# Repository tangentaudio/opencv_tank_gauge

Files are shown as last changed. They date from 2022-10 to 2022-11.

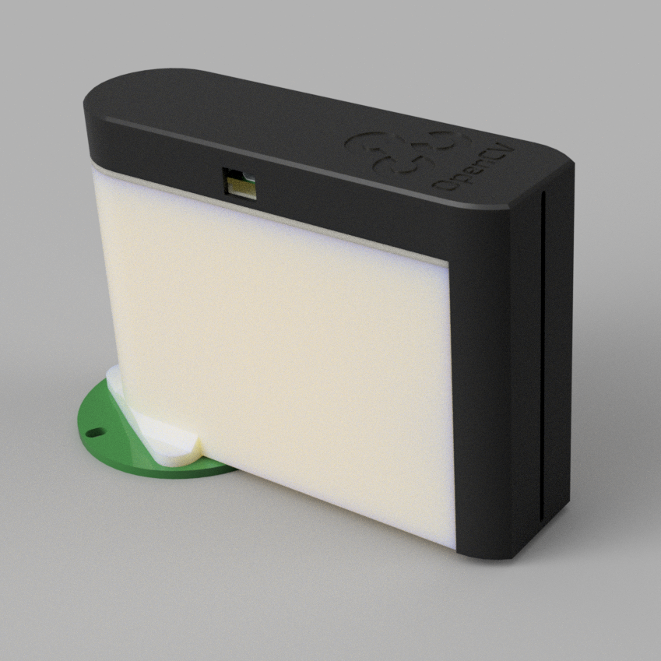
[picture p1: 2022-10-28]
mechanical/enclosure.png

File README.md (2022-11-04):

# OpenCV Oil Tank Gauge Reader

OpenCV Oil Tank Gauge Reader

## Features
- Raspberry Pi Zero W with Official Raspberry Pi Camera 2
- Custom 3D printed enclosure and tank mount, using magnets for quick removal
- 16 RGB LED display to show tank level and warnings
- Real-time CV parameter tuning with live video update in browser window
- Home Assistant API integration
- REST API

## Documentation

Full mechanical assembly, electronics assembly, and software installation instructions are located on the [Project Wiki](https://github.com/tangentaudio/opencv_tank_gauge/wiki)

## Software Quick Start

Advanced users can skip straight to the installer script, which installs all pre-requisites and configures system services.  Find it at `install.sh` in the project root directory.  This is best done on a fresh Raspberry Pi OS Lite 32-bit installation. [Full installation instructions](https://github.com/tangentaudio/opencv_tank_gauge/wiki/Software-Installation) are on the wiki.

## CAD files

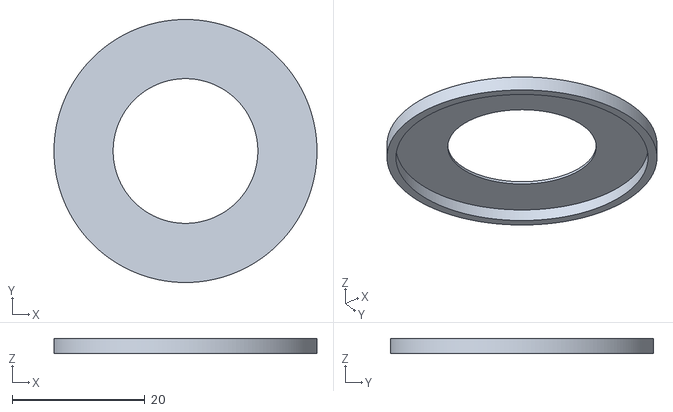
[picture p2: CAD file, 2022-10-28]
mechanical/BaseCover.stl
39.6 x 39.6 x 2.20

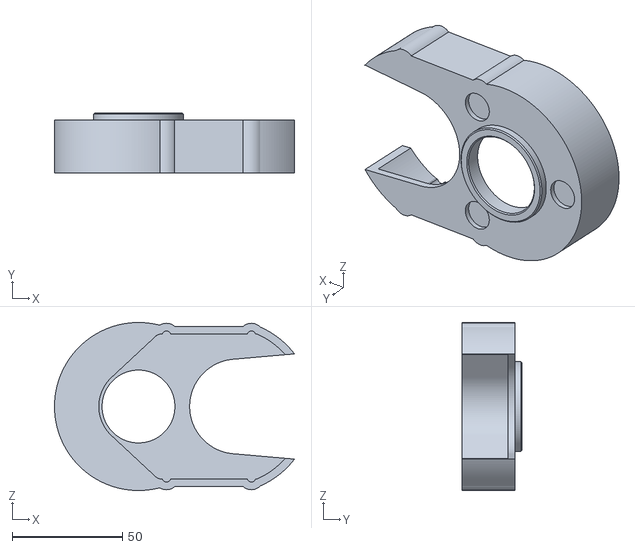
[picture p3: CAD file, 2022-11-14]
mechanical/contrib/Mounting Bracket Combo Vent Gauge.stl
108.8 x 27.4 x 76.2

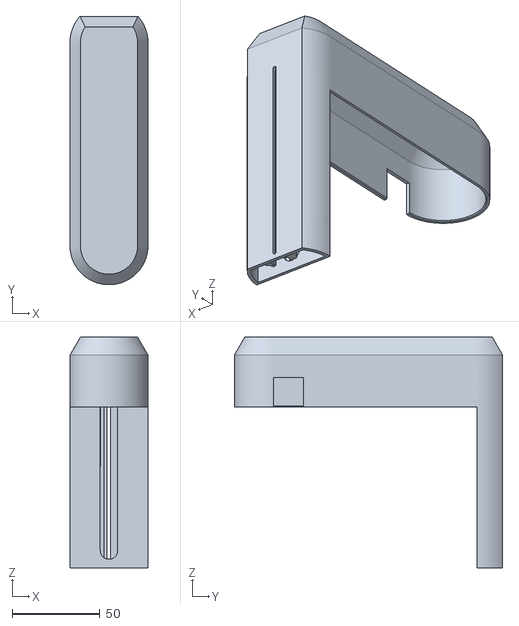
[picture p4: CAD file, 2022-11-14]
mechanical/contrib/Waveshare PoE Hat/Lid Top_PoE.stl
44.6 x 153.4 x 132.0

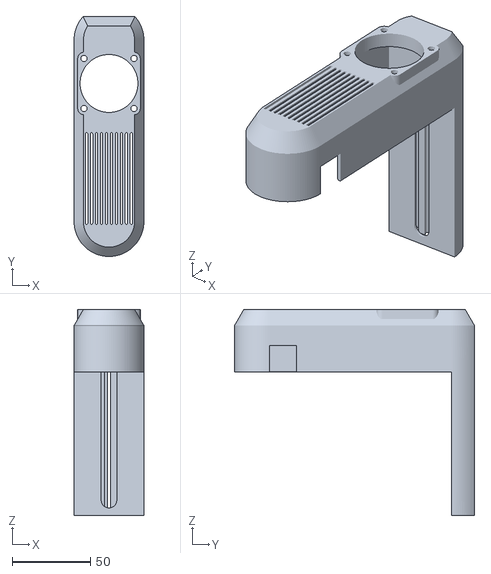
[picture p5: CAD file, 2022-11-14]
mechanical/contrib/Waveshare PoE Hat/Lid Top_PoE_Fan.stl
44.6 x 153.4 x 132.0

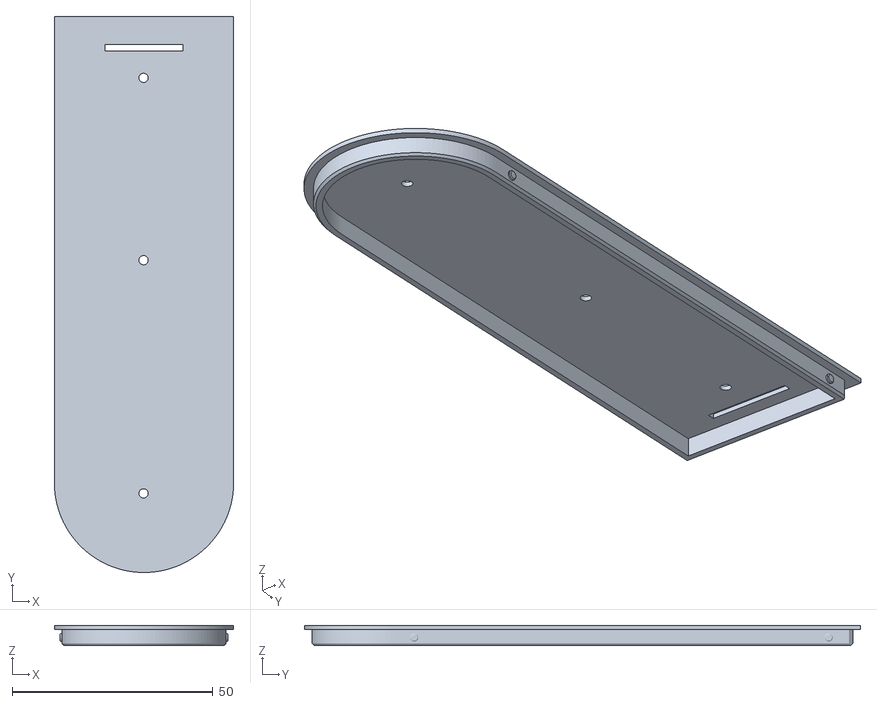
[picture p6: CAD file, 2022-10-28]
mechanical/LidLower.stl
44.6 x 138.4 x 5.00

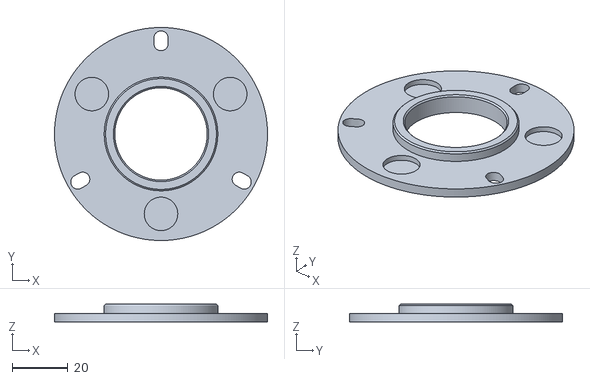
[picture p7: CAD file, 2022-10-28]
mechanical/BaseMount.stl
76.2 x 76.2 x 6.35

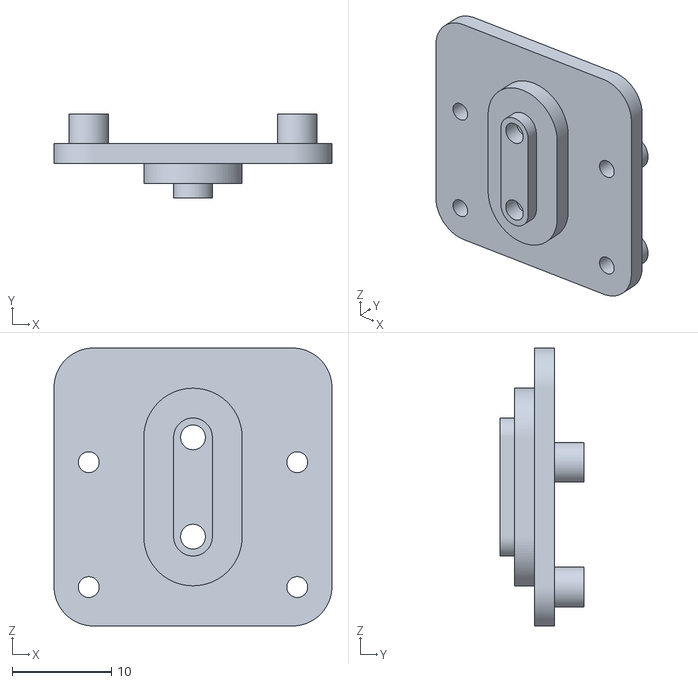
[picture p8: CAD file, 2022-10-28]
mechanical/CameraMount.stl
28.0 x 8.50 x 28.0

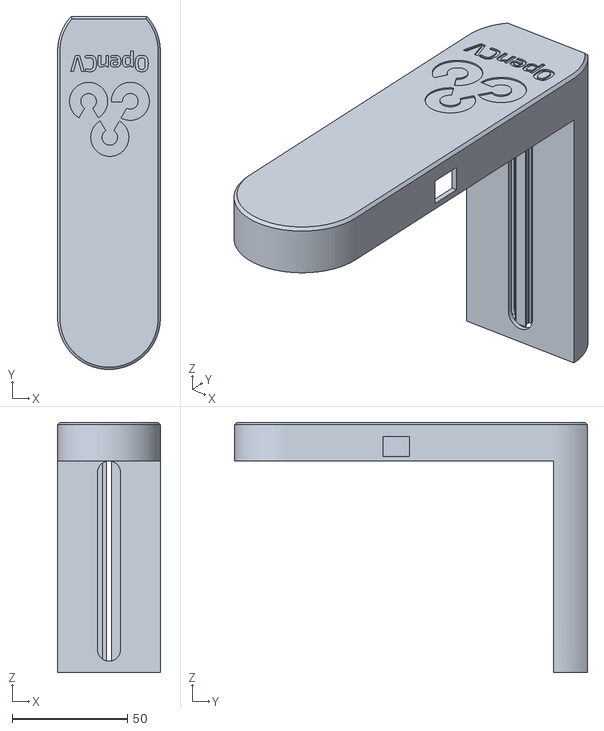
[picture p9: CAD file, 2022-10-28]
mechanical/LidTop.stl
44.6 x 153.4 x 108.8

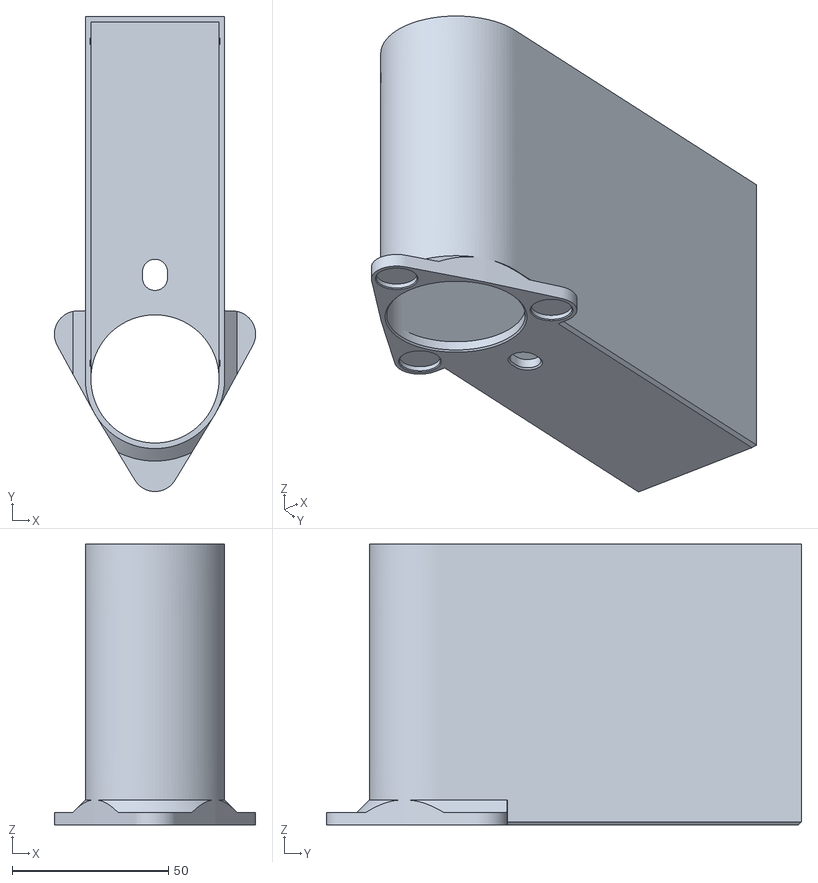
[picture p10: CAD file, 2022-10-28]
mechanical/WallStructure.stl
64.5 x 152.2 x 90.0

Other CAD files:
mechanical/LidMid.stl

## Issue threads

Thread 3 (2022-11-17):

Feature request: adjust target colors for IR cameras

timnunes, 2022-11-17:
I have an IR camera (no IR filter and IR lights that are always on) which is black/white, maybe a pinkish hue. I'm able to get this project working, but only if I shine a bright light directly on the gauge.

It detects the line segments easily (they come across as black), but the float is white with just the IR lights.

Is there a way to have it look for shades of white as opposed to shades of red?

I looked through gauge.py and found the following lines which I might be able to adjust:

```
ind_lower_red = np.array([145,112,0])
ind_upper_red = np.array([179,255,255])
```
I'm not sure what the values would be once converted to HSV.

Thanks.

tangentaudio, 2022-11-17:
Hi @timnunes,
Since the IR camera is essentially black and white, it might take a different approach to detect the position of the indicator than the one I used to find red pixels.  I'm not sure an HSV range will work well.

A good first step would be to get an unprocessed image from your setup.  Easiest thing to do would be to stop the gauge-cv service via systemctl and then run `raspistill --width 800 --height 608 --encoding png --output test.png`

Once you've got test.png, you can drop it into a comment here, e.g.:

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

timnunes, 2022-11-17:
Thanks for the reply.

First a picture with the just the built in IR lights:
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

Next is a picture with a lamp shining directly on the gauge:
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

For fun, a screenshot of the web app with the lamp turned OFF:
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

...and a screenshot of the web app with the lamp turned ON:
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

timnunes, 2022-11-18:
I may not be a smart man, but it seems that I have figured out how to adjust gauge.py to fit my needs. I'll add my edits below for anyone else looking.

In summary, I commented out the line that converts to HSV, adjusted the HTML color codes to match my camera output, and changed the reference to "ind_crop_hsv" to "ind_crop", since I'm skipping the conversion to HSV.

Thanks @tangentaudio, not only for this really great project, but also for pointing me in the right direction.

```
        # find the red indicator with a mask and range
        #ind_crop_hsv = cv2.cvtColor(ind_crop, cv2.COLOR_BGR2HSV) (commented out so no conversion happens. Optional, since we remove reference to "ind_crop_hsv" further down)

        #use an online tool to find the html colors of the float indicator in your image and adjust accordingly
        ind_lower_red = np.array([183,130,204])
        ind_upper_red = np.array([255,255,255])

        #Changed the reference from "ind_crop_hsv" to "ind_crop".
        ind_red_mask = cv2.inRange(ind_crop, ind_lower_red, ind_upper_red)
```

tangentaudio, 2022-11-18:
Glad to hear you got it working!  At some point I will make a round of improvements to the code and try to make it flexible enough to work with a setup like yours without code changes.  Cheers.

Closed 2022-11-18.

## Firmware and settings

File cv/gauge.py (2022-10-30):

#!/usr/bin/env python

import redis
from picamera import PiCamera
from picamera.array import PiRGBArray
import cv2
import numpy as np
from datetime import datetime
import time
from rich.progress import Progress

class GaugeCV:

    REQUIRED_CONFIG_KEYS = \
        ['rotate_angle',
         'crop_x1',
         'crop_x2',
         'crop_y1',
         'crop_y2',
         'slice_x1',
         'slice_x2',
         'indicator_blur',
         'tick_blur',
         'tick_threshold',
         'indicator_threshold',
         'level_average_points',
         'level_max_deviation']

    def __init__(self):
        GaugeCV.REQUIRED_CONFIG_KEYS.sort()
        
        self.rd = redis.Redis(host='localhost', port=6379, db=0)
        
        self.level_avg_win = []
        self.config = {}
        self.camera = None
        self.cam_buf = None
        self.preview = None
        self.avg = 0.0
        self.avg_update_time = None

        self.mean = None
        self.std_dev = None
        self.no_outliers = None

    def run(self):
       
        with Progress() as progress:
            with PiCamera() as self.camera:
                self.camera.resolution = (800,608)
                with PiRGBArray(self.camera, size=(800, 608)) as self.cam_buf:
                    t1 = progress.add_task("Get config from redis", total=None)
                
                    while not self.get_config():
                        time.sleep(1)

                    progress.remove_task(t1)
                    progress.console.print("Got config from redis.")

                    last_frames = 0
                    t2 = progress.add_task("Processing image frames", total=None)

                    while True:
                        if not self.get_config():
                            progress.console.print("Can't get config from redis.  Quitting.")
                            exit

                        num_frames = int(self.config['level_average_points'])

                        if last_frames != num_frames:
                            progress.reset(t2, total=num_frames)
                            last_frames = num_frames
                        
                        if self.process_image():
                            progress.console.print(f"Average level {round(self.avg, 2)}%")
                            progress.reset(t2, total=num_frames)

                        progress.advance(t2)
                        
    def get_config(self):
        have_keys = []
        for key in GaugeCV.REQUIRED_CONFIG_KEYS:
            value = self.rd.get('_config_' + key)
            if value is not None:
                value = value.decode('utf-8')
                self.config[key] = float(value)
                have_keys.append(key)

        have_keys.sort()

        return GaugeCV.REQUIRED_CONFIG_KEYS == have_keys
                    
    def config_int(self, key, default=0):
        if key in self.config:
            return int(self.config[key])
        else:
            return default

    def contour_area(self, contours):
        cnt_area = []
        for i in range(0,len(contours),1):
            cnt_area.append(cv2.contourArea(contours[i]))
        list.sort(cnt_area, reverse=True)
        return cnt_area    

    def interpolate(self, tick_contours, indicator_contours, image):
        slice_x1 = self.config_int('slice_x1')
        slice_x2 = self.config_int('slice_x2')
        crop_x1 = self.config_int('crop_x1')
        crop_x2 = self.config_int('crop_x2')
        crop_y1 = self.config_int('crop_y1')
        
        tick_fp = [100.0,75.0,50.0,25.0,0.0]
        tick_yvals = []
        indicator_yval = 0

        image_h = image.shape[0]
        image_w = image.shape[1]
        legend_w = 25

        if len(tick_contours) < 5 or len(indicator_contours) < 1:
            return [None, image]

        tick_cnt_area = self.contour_area(tick_contours)
        for i in range(0, len(tick_contours), 1):
            tick_contour = tick_contours[i]
            if (cv2.contourArea(tick_contour) >= tick_cnt_area[4]):
                x,y,w,h = cv2.boundingRect(tick_contour)
                tick_yval = y + h//2
                tick_yvals.append(tick_yval)

        ind_cnt_area = self.contour_area(indicator_contours)
        for i in range(0, len(indicator_contours), 1):
            indicator_contour = indicator_contours[i]
            if (cv2.contourArea(indicator_contour) >= ind_cnt_area[0]):
                x,y,w,h = cv2.boundingRect(indicator_contour)
                indicator_yval = y + h//2

        tick_yvals.sort()

        if len(tick_yvals) == 5:

            font = cv2.FONT_HERSHEY_SIMPLEX

            for i in range(0, len(tick_yvals), 1):
                yval = tick_yvals[i] + crop_y1
                fpval = tick_fp[i]

                image=cv2.rectangle(image,(slice_x2,yval),(slice_x2 + legend_w,yval),(0,255,0),2)

                image=cv2.putText(image, "{:.0f}%".format(fpval), (slice_x2+legend_w,yval+10), font, 1.0, (0,255,0), 2, cv2.LINE_AA) 

            level = np.interp([indicator_yval], tick_yvals, tick_fp)[0]

            image=cv2.rectangle(image,(crop_x1-legend_w,indicator_yval+crop_y1),(crop_x2,indicator_yval + crop_y1),(0,0,255),3)
            image=cv2.putText(image, "{:.2f}%".format(level), (crop_x1-legend_w-100,indicator_yval+crop_y1+10), font, 1.0, (0,0,255), 2, cv2.LINE_AA) 

            now = datetime.now()
            dt_string = now.strftime("%m/%d/%Y %H:%M:%S")        
            image=cv2.putText(image, dt_string, (0, image_h - 5), font, 1.0, (32,32,32), 2, cv2.LINE_AA) 

            return [level, image]
        return [None, image]

    def rotate_image(self, image, angle):
      image_center = tuple(np.array(image.shape[1::-1]) / 2)
      rot_mat = cv2.getRotationMatrix2D(image_center, angle, 1.0)
      result = cv2.warpAffine(image, rot_mat, image.shape[1::-1], flags=cv2.INTER_LINEAR)
      return result

    def preview_render_list(self, preview, l, x, y = 0, color=(0,0,0)):
        if preview is not None:
            pi = 0
            font = cv2.FONT_HERSHEY_SIMPLEX
            for pv in l:
                preview = cv2.putText(preview, "{:02d}: {:.2f}".format(pi, pv), (x, y + (pi+1) * 16), font, 0.5, color, 1, cv2.LINE_AA)
                pi = pi + 1
        
        return preview

    def preview_render_stats(self, preview, mean, std_dev, mean_clean):
        x = 600
        y = 0
        if preview is not None:
            font = cv2.FONT_HERSHEY_SIMPLEX
            preview = cv2.putText(preview, "MEAN: {:.2f}".format(mean), (x, y + 16), font, 0.5, (128,0,0), 1, cv2.LINE_AA)
            preview = cv2.putText(preview, "STD DEV: {:.2f}".format(std_dev), (x, y + 32), font, 0.5, (128,0,0), 1, cv2.LINE_AA)

            preview = cv2.putText(preview, "AVG: {:.2f}".format(mean_clean), (x, y + 48), font, 0.5, (0,0,128), 1, cv2.LINE_AA)
        return preview
    
    def average_level(self, level, preview):
        level_average_points = self.config_int('level_average_points')
        max_deviations = self.config['level_max_deviation']
        
        if len(self.level_avg_win) < level_average_points:
            self.level_avg_win.append(level)

            preview = self.preview_render_list(preview, self.level_avg_win, 0)

            if self.mean is not None and self.std_dev is not None and self.no_outliers is not None:
                preview = self.preview_render_list(preview, self.no_outliers, 100, 0, (64,0,0))
                preview = self.preview_render_stats(preview, self.mean, self.std_dev, self.avg)
                
        else:
            avg_array = np.array(self.level_avg_win)
            mean = np.mean(avg_array)
            standard_deviation = np.std(avg_array)
            distance_from_mean = abs(avg_array - mean)

            not_outlier = distance_from_mean <= max_deviations * standard_deviation
            no_outliers = avg_array[not_outlier]

            preview = self.preview_render_list(preview, self.level_avg_win, 0, 0)
            preview = self.preview_render_list(preview, no_outliers, 100, 0, (64,0,0))
            
            avg = np.mean(no_outliers)

            preview = self.preview_render_stats(preview, mean, standard_deviation, avg)

            self.mean = mean
            self.std_dev = standard_deviation
            self.no_outliers = no_outliers
            
            self.level_avg_win = []

            return avg, preview

        return None, preview

    def process_image(self):
        crop_x1 = self.config_int('crop_x1')
        crop_y1 = self.config_int('crop_y1')
        crop_x2 = self.config_int('crop_x2')
        crop_y2 = self.config_int('crop_y2')
        slice_x1 = self.config_int('slice_x1')
        slice_x2 = self.config_int('slice_x2')
        rotate_angle = self.config['rotate_angle']
        tick_blur = int(self.config['tick_blur'])
        indicator_blur = int(self.config['indicator_blur'])
        tick_threshold = self.config['tick_threshold']
        indicator_threshold = self.config['indicator_threshold']
        
        # capture a frame from the camera
        self.cam_buf.truncate(0)
        self.camera.capture(self.cam_buf, format="bgr")
        frame = self.cam_buf.array

        # crop and rotate the image to correct, then 180 degrees because of upside down camera
        image = self.rotate_image(frame, rotate_angle)
        image = cv2.rotate(image, 1, cv2.ROTATE_180)

        # create a preview image for the web stream
        preview = image.copy()

        # crop a slice to find the tick marks
        tick_crop = image[crop_y1:crop_y2, slice_x1:slice_x2]

        # convert to an inverted threshold image to find the tick marks
        tick_crop_gray = cv2.cvtColor(tick_crop, cv2.COLOR_BGR2GRAY)
        tick_crop_gray = cv2.blur(tick_crop_gray, (tick_blur,tick_blur), cv2.BORDER_DEFAULT)
        ret, tick_thresh = cv2.threshold(tick_crop_gray, tick_threshold, 255, cv2.THRESH_BINARY)
        tick_thresh_inv = cv2.bitwise_not(tick_thresh)

        # copy the inverted threshold image onto the preview image in the correct location
        tick_thresh_inv_bgr = cv2.cvtColor(tick_thresh_inv, cv2.COLOR_GRAY2BGR)
        tick_thresh_inv_bgr = cv2.bitwise_or(tick_crop, tick_thresh_inv_bgr)
        preview[crop_y1:crop_y1 + tick_crop.shape[0], slice_x1:slice_x1+tick_crop.shape[1]] = tick_thresh_inv_bgr

        # find contours that represent the tick marks
        tick_contours, tick_hierarchy = cv2.findContours(image=tick_thresh_inv, mode=cv2.RETR_TREE, method=cv2.CHAIN_APPROX_NONE)

        # crop a rectangle from the image to find the indicator
        ind_crop = image[crop_y1:crop_y2, crop_x1:crop_x2]

        # find the red indicator with a mask and range
        ind_crop_hsv = cv2.cvtColor(ind_crop, cv2.COLOR_BGR2HSV)

        ind_lower_red = np.array([145,112,0])
        ind_upper_red = np.array([179,255,255])

        ind_red_mask = cv2.inRange(ind_crop_hsv, ind_lower_red, ind_upper_red)
        ind_masked = cv2.bitwise_and(ind_crop, ind_crop, mask=ind_red_mask)
        ind_masked = cv2.blur(ind_masked, (indicator_blur,indicator_blur), cv2.BORDER_DEFAULT)

        ind_masked_gray = cv2.cvtColor(ind_masked, cv2.COLOR_BGR2GRAY)
        ret, ind_masked_thresh = cv2.threshold(ind_masked_gray, indicator_threshold, 255, cv2.THRESH_BINARY)

        # copy the indicator threshold image onto the preview
        prev_ind_thresh = cv2.cvtColor(ind_masked_thresh, cv2.COLOR_GRAY2BGR)
        prev_ind_thresh = cv2.bitwise_or(ind_crop, prev_ind_thresh)

        preview[crop_y1:crop_y1 + prev_ind_thresh.shape[0], crop_x1:crop_x1+prev_ind_thresh.shape[1]] = prev_ind_thresh

        # find contours for the indicator
        ind_contours, ind_hierarchy = cv2.findContours(image=ind_masked_thresh, mode=cv2.RETR_TREE, method=cv2.CHAIN_APPROX_SIMPLE)

        # draw the crops on the preview
        preview = cv2.rectangle(preview, (crop_x1, crop_y1), (crop_x2, crop_y2), (0,32,192), 2)
        preview = cv2.rectangle(preview, (slice_x1, crop_y1), (slice_x2, crop_y2), (0,192,0), 2)

        level, preview = self.interpolate(tick_contours, ind_contours, preview)

        avg = None
        if level is not None:
            avg, preview = self.average_level(level, preview)
            if avg is not None:
                
                now = str(datetime.now())
                self.rd.set('avg_level', avg)
                self.rd.set('avg_update_time', now)

                self.rd.publish('avg_level', avg)
                self.rd.publish('avg_update_time', now)

                self.avg = avg
                self.avg_update_time = now
                
        if preview is not None:
            ret, buffer = cv2.imencode('.jpg', preview)
            self.rd.set('encoded_preview', buffer.tobytes())
            self.rd.publish('encoded_preview', 'updated')


        if avg is not None:
            self.rd.publish('encoded_preview', 'updated')            
            return True
        
        return False

    def close(self):
        if self.camera is not None:
            self.camera.close()

if __name__ == '__main__':
    cv = GaugeCV()
    cv.run()
    

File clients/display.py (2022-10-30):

#!/usr/bin/env python

import time
from datetime import datetime
import board
import neopixel
from threading import Thread,Lock
from enum import Enum
import redis
import os

class States(Enum):
    INIT = 1
    ERROR = 2
    QUERY = 3
    LEVEL = 4
    SHUTDOWN = 5

class GaugePixels:
    def __init__(self):
        self.pixels = neopixel.NeoPixel(board.D21, 16, brightness=0.1, pixel_order=neopixel.GRB, auto_write=False)

        self.state = States.INIT
        self.state_update = True
        self.phase = 0
        self.level = 0.0
        self.warn = False
        self.lock = Lock()
        
        t = Thread(target=self.thread_func)
        t.start()

        
    def display_level(self, level, show=True):
        print("display level={l}".format(l=level))
        self.pixels.fill((0,0,0))

        warn = False
        
        color = (0,255,0)
        if level > 0.0 and level < 30.0:
            color = (255, 0, 0)
            warn = True
        elif level >= 30 and level < 70:
            color = (192, 192, 0)
            
        last = int(15 * (level / 100.0)) + 1;
            
        for pixel in range(0,last,1):
            self.pixels[pixel] = color

        if show:
            self.pixels.show()
        
        return [warn, last]
       
        
    def thread_func(self):
        while True:
            with self.lock:
                state = self.state
                state_update = self.state_update
                phase = self.phase
                level = self.level
                warn = self.warn

            if state_update:
                phase = 0
            else:
                phase = phase + 1
                
            if state == States.INIT:
                if phase == 0:
                    self.pixels.fill((0,0,255))
                    self.pixels.show()
                elif phase == 10:
                    self.pixels.fill((0,0,0))
                    self.pixels.show()
                pass
            elif state == States.ERROR:
                if phase == 0:
                    self.pixels.fill((255,0,0))
                    self.pixels.show()
                elif phase == 5:
                    self.pixels.fill((0,0,0))
                    self.pixels.show()
                elif phase == 10:
                    phase = 0
                pass
            elif state == States.QUERY:
                if phase == 0:
                    self.pixels.fill((0,0,0))
                    self.pixels.show()
                elif phase == 3:
                    self.pixels[6] = (0,0,255)
                    self.pixels[7] = (255,255,255)
                    self.pixels[8] = (0,0,255)
                    self.pixels.show()
                elif phase == 6:
                    phase = 0
                    
            elif state == States.LEVEL:
                if phase == 0:
                    # show level and top LED as blue to indicate an update
                    warn, last = self.display_level(level, False)
                    self.pixels[15] = (0, 0, 255)
                    self.pixels.show()

                elif phase == 10:
                    # show the plain level
                    warn, last = self.display_level(level, True)
                    
                elif phase == 15:
                    # blink the level if in warning state
                    if warn:
                        self.pixels.fill((0,0,0))
                        self.pixels.show()

                elif phase == 20:
                    # jump back to plain level display in warning state
                    if warn:
                        phase = 10
                    
            elif state == States.SHUTDOWN:
                if phase == 0:
                    self.pixels.fill((0,0,0))
                    self.pixels[0] = (255, 255, 255)
                    self.pixels.show()
                        
            else:
                pass

            time.sleep(0.100)

            with self.lock:
                if state_update:
                    self.state_update = False
                self.phase = phase
                self.warn = warn
                

                	

    def set_state(self, state):
        with self.lock:
            self.state = state
            self.state_update = True

        print("set state={s}".format(s=state))
              
    def set_level(self, level):
        with self.lock:
            self.level = level

        print("set level={l}".format(l=level))
        
if __name__ == '__main__':
    gauge = GaugePixels()
   
    rd = redis.Redis(host='localhost', port=6379, db=0, charset='utf-8', decode_responses=True)
    sub = rd.pubsub()
    
    sub.subscribe('avg_level', 'avg_update_time', 'shutdown')
    while True:
        for msg in sub.listen():
            if msg['type'] == 'message':
                c = msg['channel']
                d = msg['data']
            
                if c == 'avg_level':
                    level = float(d)
                elif c == 'avg_update_time':
                    update_time = datetime.strptime(d, '%Y-%m-%d %H:%M:%S.%f')
                    age = (datetime.now() - update_time).total_seconds()

                    if (age < 600.0):
                        gauge.set_level(level)
                        gauge.set_state(States.LEVEL)

                    else:
                        gauge.set_state(States.ERROR)
                elif c == 'shutdown':
                    gauge.set_state(States.SHUTDOWN)
                    time.sleep(1)
                    if d == 'reboot':
                        os.system('/usr/sbin/reboot')
                    else:
                        os.system('/usr/sbin/poweroff -f')
                        

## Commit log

2022-10-20 initial demo/prototype code
2022-10-20 rework to run for one cycle for cron
    [gauge.py]
2022-10-20 bugfix in contour checks tweaks for different lighting
    [gauge.py]
2022-10-24 add command line, rework tuning preview image
    [gauge.py]
2022-10-25 hacky camera busy detection to avoid conflict between tune mode and level acq mode
    [gauge.py, gaugecv.py, webapp.py]
2022-10-26 move cv to thread
2022-10-27 rework display client to use redis
    [display.py, gauge.py]
2022-10-28 rework tuning to use spinners, add indicator thresh config, other tweaks
    [gauge.py]
2022-10-28 add 3D print model STL (v42), tuner screenshot
    [BaseCover.stl, BaseMount.stl, CameraMount.stl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]
2022-10-29 remove unnecessary thread from gauge cv process, use python rich for pretty output
2022-10-29 implement system shutdown and reboot functions from tuning page
    [display.py]
2022-10-29 shutdown LED state
2022-10-30 tweaks for venv and other fixes found during installer work
    [display.py, gauge.py, hass.py]
2022-11-12 Adding new files to mechanical that support combo gauge and vent installs. New cover design allows use of waveshare PoE hat
    [Lid Top_PoE.stl, Lid Top_PoE_Fan.stl, Mounting Bracket Combo Vent Gauge.stl]
